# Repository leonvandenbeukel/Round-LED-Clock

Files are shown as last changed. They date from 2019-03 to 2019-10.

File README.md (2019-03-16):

# Wi-Fi Connected Round-LED-Clock
 
 ### Schema
 
 Connect 5 volts from the micro usb breakout board to the 5 volt pin on the ESP module.  
 Connect Ground from the micro usb breakout board to the Ground on the ESP module.  
 Connect 5 volts from the usb breakout board to 5 volt on the LED strip.  
 Connect Ground from the usb breakout board to Ground on the LED strip.  
 Connect pin D6 from the ESP module to the Data line on the LED strip.  
 
 ### Parts list (just Google on the name to find a link where to buy)

| Components                              			       |
| -------------                          			        |
| WeMOS D1 Mini ESP module               			        |
| LED strip WS2812B 60 RGB LED's 1 meter            |
| Black PLA filament                           		   |
| White PLA filament                           		   |
| 4x M3 screws                                      |
| 5 Volt power adapter                              |
| Micro USB cable                                   |
| Jumper wires                                      |
| Mini breadboard                                   |
| Micro USB breakout board                          |

### YouTube video

<a href="https://youtu.be/Z4b4v84smpg" target="_blank">Click to view: LED Clock</a>

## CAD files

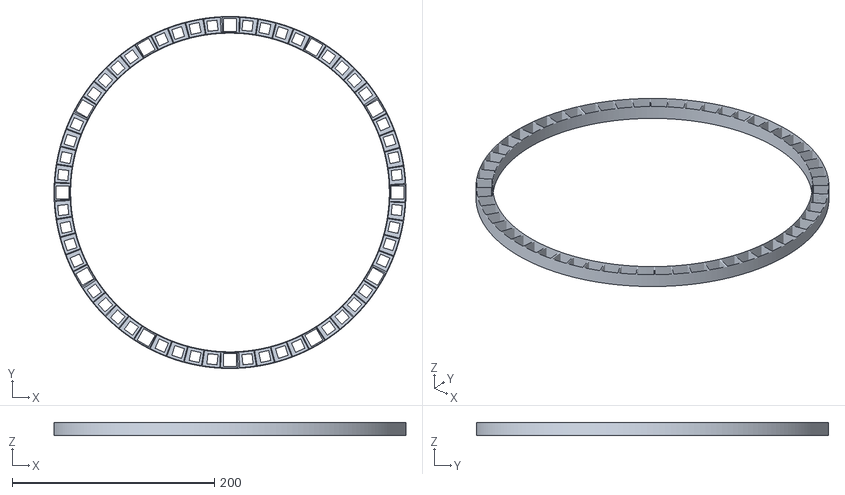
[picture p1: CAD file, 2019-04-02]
STL/Segment complete.stl
348.1 x 348.1 x 13.2

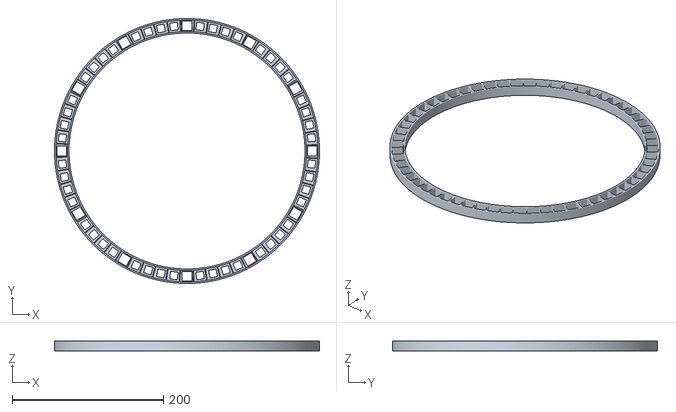
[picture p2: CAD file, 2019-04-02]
STL/Segment complete thicker wall.stl
350.9 x 350.9 x 13.2

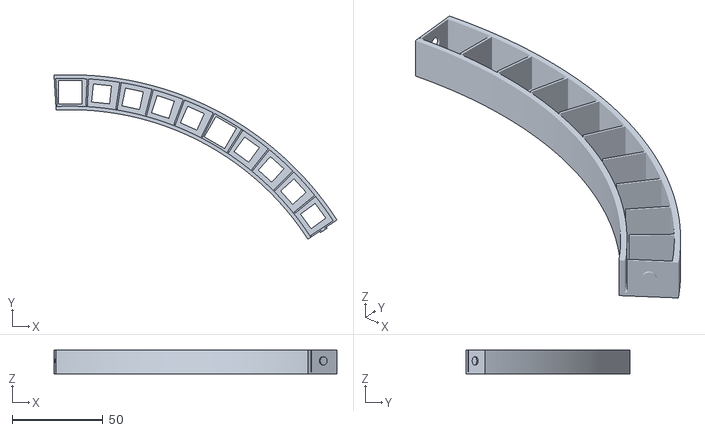
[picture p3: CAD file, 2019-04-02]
STL/Segment thicker wall.stl
156.2 x 90.7 x 13.2

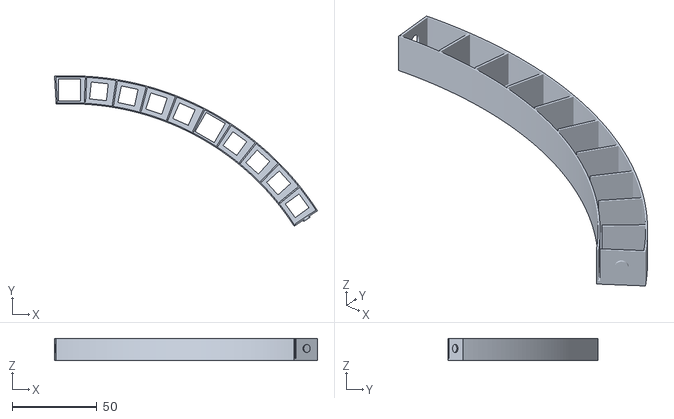
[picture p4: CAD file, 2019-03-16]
STL/Segment.stl
154.9 x 88.6 x 13.2

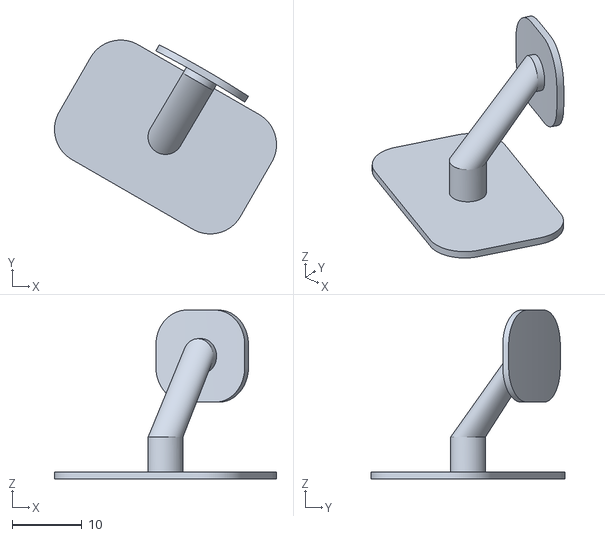
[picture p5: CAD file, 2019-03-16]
STL/Holder Small.stl
31.8 x 27.8 x 24.2

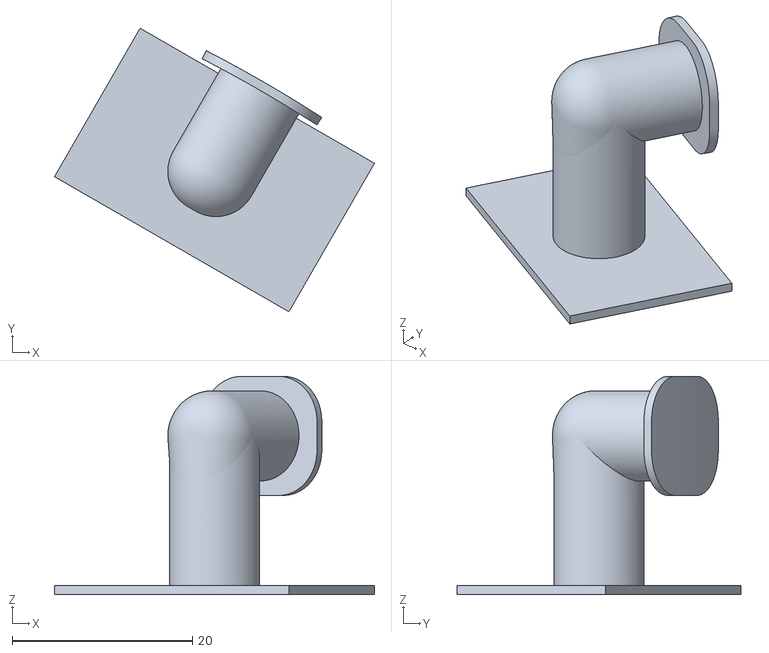
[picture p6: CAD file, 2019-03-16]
STL/Holder Large.stl
35.5 x 31.4 x 24.2

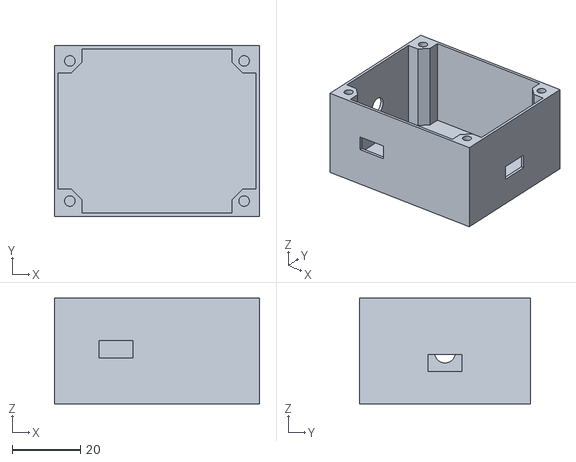
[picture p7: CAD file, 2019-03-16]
STL/Box.stl
60.0 x 50.0 x 31.0

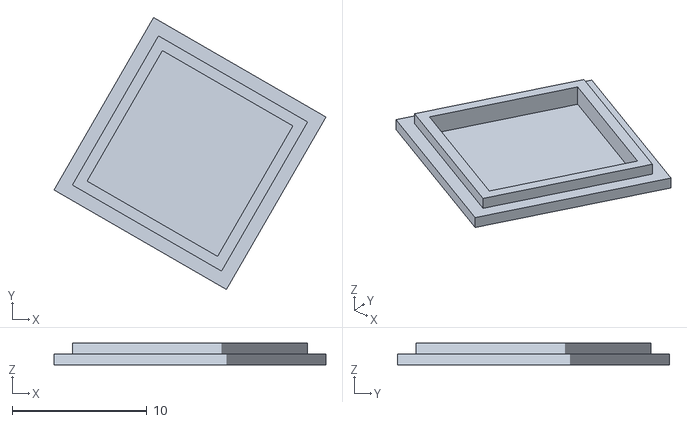
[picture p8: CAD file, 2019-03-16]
STL/Cover Large.stl
20.2 x 20.2 x 1.60

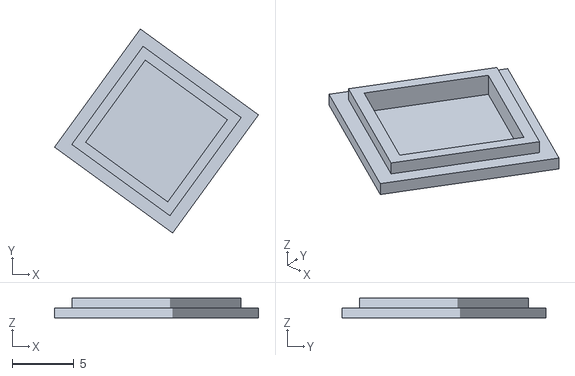
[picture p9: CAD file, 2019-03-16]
STL/Cover Small.stl
16.5 x 16.5 x 1.60

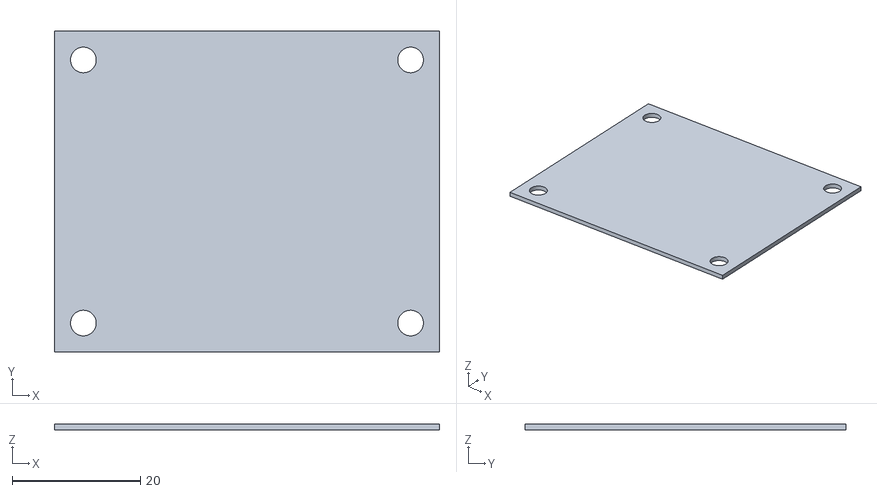
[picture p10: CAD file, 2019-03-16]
STL/Lid.stl
60.0 x 50.0 x 1.00

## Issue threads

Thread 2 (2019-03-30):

File request and your SMTP could be down

potter-91, 2019-03-30:
Hi Leon,

I tried to send a mail to your youtube mail, the mail got a delivery error at your smtp server.
So here is my mail:

Would it be possible that you can please send mir your Fusion Project or the files as steps?
I want to print the hole ring in one part beacause m Printer is so big ^^

Greeting from Germany ^^

leonvandenbeukel, 2019-04-02:
Hi,

I've added a complete ring for you to print in the STL files. Also added a segment with thicker walls as someone else requested.

Greetings from the Netherlands :-)
Leon

Closed 2019-04-02.

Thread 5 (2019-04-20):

Frequent Change to false time

arne4, 2019-04-20:
The LEDs show a wrong time every few minutes or seconds. This false indication lasts less than a second.
- I replaced the wemos, but nothing has changed.
- Solder connection also new and no change

Is this behaviour known or what else could it be?
Normally I would guess a problem with the wemos, but that should be excluded.

Thank you, Arne

ThEWiZ76, 2019-04-21:
Same problem here https://www.youtube.com/watch?v=w4xsj8hr7YY

ThEWiZ76, 2019-04-21:
I've merged the nighttime/hour gold/colormixing pull requests in the version I am running, then the problem is more visible. It looks like the whole register shifts forward. I think it's a FastLED lib issue rather than the code of this project. I currently use 3.1.6 and you?

ThEWiZ76, 2019-04-22:
I've done a little bit of reading, some people say the issue can occur when the power supply to the led strip isn't sufficient. I have upgraded my library to 3.2.6 and my issue is resolved.

arne4, 2019-04-23:
I upgraded to 3.2.6 and changed the power supply (also with direct supply of the LEDs) but unfortunately no change in behaviour....

:(
Such a beautiful clock, but currently it is not working!

arne4, 2019-04-23:
I just realised, that my IDE tricked me... I thought I updated to 3.2.6, but actually I still stick to the old FASTled library.
NOW, I updated and also everything is fine!
Thanks for this wonderful clock!
Arne

Closed 2019-04-23.

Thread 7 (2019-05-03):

Hour LED moving between hours

tomtaa, 2019-05-03:
Great work, but one issue:
At a normal analog clock the hour hand moves always.
e.g. at 9:30 the big hand is between 9 and 10.
At your device it stays on the 9.
Special at e.g. 9:55 your hour hand stays at 9; at the analog clock it stays directly before 10.

It's a little bit unusual.

Mahekrana, 2019-05-04:
can you share  videoof program uploadin eps8266 board

tomtaa, 2019-05-05:
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

I show here a sketch about that, what I mean. It's no technical problem with the clock; it's only a different to a normal analog clock. Maybe it's also a pull request and no issue.

arne4, 2019-05-05:
Hi,
as I understood the hour LED is not moving within the 5 possible positions during the course of the 60 min.
You would expect, that every ~15 min the hour LED moves towards the next Hour; the current sketch does not provide this functionality. The hour LED stays on the same spot for 1 hour and then moves 5 positions further.

Maybe someone can update the sketch with the following functionality:
1) introduce an hour_offset value
2)    if (minute>=10)
    hour_offset=(minute / 10)-1;
  else
    hour_offset=0;
3) hour_offset should move the hour LED acc to the value in hour_offset.

I am currently trying to update the sketch, but unfortunately (until now) I am not successfull ;)

tomtaa, 2019-05-05:
So, I play a little bit

and add one value and one additional row.

it seems to work, but I don't know if it works in all cases.
Maybe someone has the profi solution.
row 112 ff

`    for (int i=0; i<NUM_LEDS; i++)
      LEDs[i] = CRGB::Black;

      LEDs[getLEDMinuteOrSecond(currentDateTime.second)] = colorSecond;
      int stunde = (getLEDHour(currentDateTime.hour) + (currentDateTime.minute / 12)); //to move the Big Hand every 12 minutes
      LEDs[stunde] = colorHour; //to move the Big Hand every 12 minutes
    //LEDs[getLEDHour(currentDateTime.hour)] = colorHour; //Original

    LEDs[getLEDMinuteOrSecond(currentDateTime.minute)] = colorMinute;

    FastLED.show();`

arne4, 2019-05-06:
Hi there,

tried to get it running, but with no luck :(
I have two Hour spots now...
(tried to incrporate your into the existing code...)

Thank you, Arne

leonvandenbeukel, 2019-05-10:
Thanks for the suggestion and ideas! I've modified the code, you can use USE_LED_MOVE_BETWEEN_HOURS to enable this option.

Closed 2019-05-10.

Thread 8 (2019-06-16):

Newbie error in  compiling/flashing

RafaelCota, 2019-06-16:
Hi,
I'm trying to flash the program to the controller, but I'm getting some errors (files attached)

I was wondering if you could put me in the right track. I really want to get this project done. It's a good one.

Thank you in advanced,

[Errors-NonVerbose.pdf](https://github.com/leonvandenbeukel/Round-LED-Clock/files/3294463/Errors-NonVerbose.pdf)
[Errors-Verbose.pdf](https://github.com/leonvandenbeukel/Round-LED-Clock/files/3294464/Errors-Verbose.pdf)

leonvandenbeukel, 2019-06-16:
Hi,

If you use a generic esp board you probably cannot use pin D6, try using
only the pin number.

Regards,
Leon

Op zo 16 jun. 2019 20:45 schreef RafaelCota <notifications@github.com>:

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

Closed 2019-10-06.

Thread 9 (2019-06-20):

compilation error

Pierre01480, 2019-06-20:
Hello Leon,
I am admiring of all yours creations . Great !
I would like to make the WIFI clock (with the Wemos d1 mini board)
I selected the board LOLIN (Wemos) D1 R2 & mini (in the choise list of boards there is no Wemos D1 mini)
Below is the error message when compiling
Since 3 weeks I try to solve the problem .... Without success
If I use the library Adafruit_Neopixel (of course by modifying your program a bit): it works .... But I would like to understand my mistake
Thanks for your help

[errors.pdf](https://github.com/leonvandenbeukel/Round-LED-Clock/files/3310986/errors.pdf)

ThEWiZ76, 2019-06-21:
You should upgrade your fastled library to at least 3.2.6

Pierre01480, 2019-06-21:
thanks a lot for your help

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

Closed 2019-10-06.

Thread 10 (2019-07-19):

.

alhaddar, 2019-07-19:

alhaddar, 2019-07-19:
The problem has been resolved

alhaddar, 2019-07-20:
In file included from C:\Users\alhaddar\Round-LED-Clock_f-home2\Round-LED-Clock_f-home2.ino:18:0:

C:\Users\alhaddar\Documents\Arduino\libraries\FastLED/FastLED.h:14:21: note: #pragma message: FastLED version 3.002.010

 #    pragma message "FastLED version 3.002.010"

                     ^

In file included from C:\Users\alhaddar\Documents\Arduino\libraries\FastLED/FastLED.h:65:0,

                 from C:\Users\alhaddar\Round-LED-Clock_f-home2\Round-LED-Clock_f-home2.ino:18:

C:\Users\alhaddar\Documents\Arduino\libraries\FastLED/fastspi.h:115:23: note: #pragma message: No hardware SPI pins defined.  All SPI access will default to bitbanged output

 #      pragma message "No hardware SPI pins defined.  All SPI access will default to bitbanged output"

                       ^

Closed 2019-07-20.

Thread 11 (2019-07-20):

#pragma message: FastLED version 3.002.010

alhaddar, 2019-07-20:
Hi
Hi
When I'm sending programs to the Arduino show me this message

In file included from C:\Users\alhaddar\Round-LED-Clock_f-home2\Round-LED-Clock_f-home2.ino:18:0:

C:\Users\alhaddar\Documents\Arduino\libraries\FastLED/FastLED.h:14:21: note: #pragma message: FastLED version 3.002.010

 #    pragma message "FastLED version 3.002.010"

                     ^

In file included from C:\Users\alhaddar\Documents\Arduino\libraries\FastLED/FastLED.h:65:0,

                 from C:\Users\alhaddar\Round-LED-Clock_f-home2\Round-LED-Clock_f-home2.ino:18:

C:\Users\alhaddar\Documents\Arduino\libraries\FastLED/fastspi.h:115:23: note: #pragma message: No hardware SPI pins defined.  All SPI access will default to bitbanged output

 #      pragma message "No hardware SPI pins defined.  All SPI access will default to bitbanged output"

                       ^

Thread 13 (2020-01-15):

Minute and hour hand jumps to new position when second is at 59 and sometimes 30.

jldortch, 2020-01-15:
After resolving my initial problem my libraries, I built two clocks. both have the same strange action at the same times. condition only lasts for the one second...

Japyh, 2021-01-15:
Hi,
I have used the code for another clock design but the coding is the same. I measured the same problem of switching hours to the section of minutes after some time.
The code was implemented 1:1 and I use a APA106 F5 Led string which is controlled by the library fastLED and the SK6822 chipset.
Has somebody an idea of how to solv it?

Thanks in advance for an answer and best regards,
JP

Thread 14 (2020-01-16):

'D6' was not declared in this scope

rf5g, 2020-01-16:
when sending i have this error:
'D6' was not declared in this scope

i try:
#define DATA_PIN 6
error:
Compilation Error for Generic ESP8266 Module Board.

how i can solve this problem?

rf5g, 2020-01-17:
Because my ESP8266 Mini d1 have different pin names. D6 = gpio12. Sorry...

Closed 2020-01-17.

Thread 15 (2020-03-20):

DATA_PIN not defined in the scope

raviteja2110, 2020-03-20:
Round-LED-Clock:81:18: error: 'D6' was not declared in this scope

 #define DATA_PIN D6

Pijuli, 2020-03-21:
Same here :(

Pijuli, 2020-03-21:
Using ESP8266 D1 mini
This is what I'm getting. Any idea?

`Arduino:1.8.12 (Windows 10), Tarjeta:"Generic ESP8266 Module, 80 MHz, Flash, Legacy (new can return nullptr), All SSL ciphers (most compatible), dtr (aka nodemcu), 26 MHz, 40MHz, DOUT (compatible), 1MB (FS:64KB OTA:~470KB), 2, nonos-sdk 2.2.1+100 (190703), v2 Lower Memory, Disabled, None, Only Sketch, 115200"

In file included from C:\Users\Pijuli\Documents\Arduino\projectes\Round-LED-Clock\Round-LED-Clock.ino:18:0:

C:\Users\Pijuli\Documents\Arduino\libraries\FastLED/FastLED.h:14:21: note: #pragma message: FastLED version 3.003.003

 #    pragma message "FastLED version 3.003.003"

                     ^

In file included from C:\Users\Pijuli\Documents\Arduino\libraries\FastLED/FastLED.h:65:0,

                 from C:\Users\Pijuli\Documents\Arduino\projectes\Round-LED-Clock\Round-LED-Clock.ino:18:

C:\Users\Pijuli\Documents\Arduino\libraries\FastLED/fastspi.h:130:23: note: #pragma message: No hardware SPI pins defined.  All SPI access will default to bitbanged output

 #      pragma message "No hardware SPI pins defined.  All SPI access will default to bitbanged output"

                       ^

C:\Users\Pijuli\Documents\Arduino\projectes\Round-LED-Clock\Round-LED-Clock.ino: In function 'void setup()':

Round-LED-Clock:63:18: error: 'D6' was not declared in this scope

 #define DATA_PIN D6

                  ^

C:\Users\Pijuli\Documents\Arduino\projectes\Round-LED-Clock\Round-LED-Clock.ino:81:28: note: in expansion of macro 'DATA_PIN'

   FastLED.addLeds<WS2812B, DATA_PIN, GRB>(LEDs, NUM_LEDS);

                            ^

Round-LED-Clock:81:57: error: no matching function for call to 'CFastLED::addLeds(CRGB [60], int)'

   FastLED.addLeds<WS2812B, DATA_PIN, GRB>(LEDs, NUM_LEDS);

                                                         ^

C:\Users\Pijuli\Documents\Arduino\projectes\Round-LED-Clock\Round-LED-Clock.ino:81:57: note: candidates are:

In file included from C:\Users\Pijuli\Documents\Arduino\projectes\Round-LED-Clock\Round-LED-Clock.ino:18:0:

C:\Users\Pijuli\Documents\Arduino\libraries\FastLED/FastLED.h:223:130: note: template<ESPIChipsets CHIPSET, unsigned char DATA_PIN, unsigned char CLOCK_PIN, EOrder RGB_ORDER, unsigned int SPI_DATA_RATE> CLEDController& CFastLED::addLeds(CRGB*, int, int)

  template<ESPIChipsets CHIPSET,  uint8_t DATA_PIN, uint8_t CLOCK_PIN, EOrder RGB_ORDER, uint32_t SPI_DATA_RATE > CLEDController &addLeds(struct CRGB *data, int nLedsOrOffset, int nLedsIfOffset = 0) {

                                                                                                                                  ^

C:\Users\Pijuli\Documents\Arduino\libraries\FastLED/FastLED.h:223:130: note:   template argument deduction/substitution failed:

Round-LED-Clock:81:57: error: template argument 2 is invalid

   FastLED.addLeds<WS2812B, DATA_PIN, GRB>(LEDs, NUM_LEDS);

                                                         ^

In file included from C:\Users\Pijuli\Documents\Arduino\projectes\Round-LED-Clock\Round-LED-Clock.ino:18:0:

C:\Users\Pijuli\Documents\Arduino\libraries\FastLED/FastLED.h:237:95: note: template<ESPIChipsets CHIPSET, unsigned char DATA_PIN, unsigned char CLOCK_PIN> static CLEDController& CFastLED::addLeds(CRGB*, int, int)

  template<ESPIChipsets CHIPSET,  uint8_t DATA_PIN, uint8_t CLOCK_PIN > static CLEDController &addLeds(struct CRGB *data, int nLedsOrOffset, int nLedsIfOffset = 0) {

                                                                                               ^

C:\Users\Pijuli\Documents\Arduino\libraries\FastLED/FastLED.h:237:95: note:   template argument deduction/substitution failed:

Round-LED-Clock:81:57: error: template argument 2 is invalid

   FastLED.addLeds<WS2812B, DATA_PIN, GRB>(LEDs, NUM_LEDS);

                                                         ^

In file included from C:\Users\Pijuli\Documents\Arduino\projectes\Round-LED-Clock\Round-LED-Clock.ino:18:0:

C:\Users\Pijuli\Documents\Arduino\libraries\FastLED/FastLED.h:251:113: note: template<ESPIChipsets CHIPSET, unsigned char DATA_PIN, unsigned char CLOCK_PIN, EOrder RGB_ORDER> static CLEDController& CFastLED::addLeds(CRGB*, int, int)

  template<ESPIChipsets CHIPSET,  uint8_t DATA_PIN, uint8_t CLOCK_PIN, EOrder RGB_ORDER > static CLEDController &addLeds(struct CRGB *data, int nLedsOrOffset, int nLedsIfOffset = 0) {

                                                                                                                 ^

C:\Users\Pijuli\Documents\Arduino\libraries\FastLED/FastLED.h:251:113: note:   template argument deduction/substitution failed:

Round-LED-Clock:81:57: error: template argument 2 is invalid

   FastLED.addLeds<WS2812B, DATA_PIN, GRB>(LEDs, NUM_LEDS);

                                                         ^

In file included from C:\Users\Pijuli\Documents\Arduino\projectes\Round-LED-Clock\Round-LED-Clock.ino:18:0:

C:\Users\Pijuli\Documents\Arduino\libraries\FastLED/FastLED.h:301:25: note: template<template<unsigned char DATA_PIN, EOrder RGB_ORDER> class CHIPSET, unsigned char DATA_PIN, EOrder RGB_ORDER> static CLEDController& CFastLED::addLeds(CRGB*, int, int)

  static CLEDController &addLeds(struct CRGB *data, int nLedsOrOffset, int nLedsIfOffset = 0) {

                         ^

C:\Users\Pijuli\Documents\Arduino\libraries\FastLED/FastLED.h:301:25: note:   template argument deduction/substitution failed:

Round-LED-Clock:81:57: error: template argument 2 is invalid

   FastLED.addLeds<WS2812B, DATA_PIN, GRB>(LEDs, NUM_LEDS);

                                                         ^

In file included from C:\Users\Pijuli\Documents\Arduino\projectes\Round-LED-Clock\Round-LED-Clock.ino:18:0:

C:\Users\Pijuli\Documents\Arduino\libraries\FastLED/FastLED.h:307:25: note: template<template<unsigned char DATA_PIN, EOrder RGB_ORDER> class CHIPSET, unsigned char DATA_PIN> static CLEDController& CFastLED::addLeds(CRGB*, int, int)

  static CLEDController &addLeds(struct CRGB *data, int nLedsOrOffset, int nLedsIfOffset = 0) {

                         ^

C:\Users\Pijuli\Documents\Arduino\libraries\FastLED/FastLED.h:307:25: note:   template argument deduction/substitution failed:

Round-LED-Clock:81:57: error: wrong number of template arguments (3, should be 2)

   FastLED.addLeds<WS2812B, DATA_PIN, GRB>(LEDs, NUM_LEDS);

                                                         ^

In file included from C:\Users\Pijuli\Documents\Arduino\projectes\Round-LED-Clock\Round-LED-Clock.ino:18:0:

C:\Users\Pijuli\Documents\Arduino\libraries\FastLED/FastLED.h:313:25: note: template<template<unsigned char DATA_PIN> class CHIPSET, unsigned char DATA_PIN> static CLEDController& CFastLED::addLeds(CRGB*, int, int)

  static CLEDController &addLeds(struct CRGB *data, int nLedsOrOffset, int nLedsIfOffset = 0) {

                         ^

C:\Users\Pijuli\Documents\Arduino\libraries\FastLED/FastLED.h:313:25: note:   template argument deduction/substitution failed:

Round-LED-Clock:81:57: error: wrong number of template arguments (3, should be 2)

   FastLED.addLeds<WS2812B, DATA_PIN, GRB>(LEDs, NUM_LEDS);

                                                         ^

In file included from C:\Users\Pijuli\Documents\Arduino\projectes\Round-LED-Clock\Round-LED-Clock.ino:18:0:

C:\Users\Pijuli\Documents\Arduino\libraries\FastLED/FastLED.h:357:25: note: template<template<EOrder RGB_ORDER> class CHIPSET, EOrder RGB_ORDER> static CLEDController& CFastLED::addLeds(CRGB*, int, int)

  static CLEDController &addLeds(struct CRGB *data, int nLedsOrOffset, int nLedsIfOffset = 0) {

                         ^

C:\Users\Pijuli\Documents\Arduino\libraries\FastLED/FastLED.h:357:25: note:   template argument deduction/substitution failed:

Round-LED-Clock:81:57: error: wrong number of template arguments (3, should be 2)

   FastLED.addLeds<WS2812B, DATA_PIN, GRB>(LEDs, NUM_LEDS);

                                                         ^

In file included from C:\Users\Pijuli\Documents\Arduino\projectes\Round-LED-Clock\Round-LED-Clock.ino:18:0:

C:\Users\Pijuli\Documents\Arduino\libraries\FastLED/FastLED.h:363:25: note: template<template<EOrder RGB_ORDER> class CHIPSET> static CLEDController& CFastLED::addLeds(CRGB*, int, int)

  static CLEDController &addLeds(struct CRGB *data, int nLedsOrOffset, int nLedsIfOffset = 0) {

                         ^

C:\Users\Pijuli\Documents\Arduino\libraries\FastLED/FastLED.h:363:25: note:   template argument deduction/substitution failed:

Round-LED-Clock:81:57: error: wrong number of template arguments (3, should be 1)

   FastLED.addLeds<WS2812B, DATA_PIN, GRB>(LEDs, NUM_LEDS);

                                                         ^

In file included from C:\Users\Pijuli\Documents\Arduino\projectes\Round-LED-Clock\Round-LED-Clock.ino:18:0:

C:\Users\Pijuli\Documents\Arduino\libraries\FastLED/FastLED.h:431:25: note: template<EBlockChipsets CHIPSET, int NUM_LANES, EOrder RGB_ORDER> static CLEDController& CFastLED::addLeds(CRGB*, int, int)

  static CLEDController &addLeds(struct CRGB *data, int nLedsOrOffset, int nLedsIfOffset = 0) {

                         ^

C:\Users\Pijuli\Documents\Arduino\libraries\FastLED/FastLED.h:431:25: note:   template argument deduction/substitution failed:

Round-LED-Clock:81:57: error: template argument 2 is invalid

   FastLED.addLeds<WS2812B, DATA_PIN, GRB>(LEDs, NUM_LEDS);

                                                         ^

In file included from C:\Users\Pijuli\Documents\Arduino\projectes\Round-LED-Clock\Round-LED-Clock.ino:18:0:

C:\Users\Pijuli\Documents\Arduino\libraries\FastLED/FastLED.h:472:25: note: template<EBlockChipsets CHIPSET, int NUM_LANES> static CLEDController& CFastLED::addLeds(CRGB*, int, int)

  static CLEDController &addLeds(struct CRGB *data, int nLedsOrOffset, int nLedsIfOffset = 0) {

                         ^

C:\Users\Pijuli\Documents\Arduino\libraries\FastLED/FastLED.h:472:25: note:   template argument deduction/substitution failed:

Round-LED-Clock:81:57: error: wrong number of template arguments (3, should be 2)

   FastLED.addLeds<WS2812B, DATA_PIN, GRB>(LEDs, NUM_LEDS);

                                                         ^

exit status 1
'D6' was not declared in this scope

Este informe podría contener más información con
"Mostrar salida detallada durante la compilación"
opción habilitada en Archivo -> Preferencias.
`

Pijuli, 2020-03-21:
Fixed.
I was using the wrong ESP8266 board
Tripple check your board. In my case WEMOS D1 R2 & Mini

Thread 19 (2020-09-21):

No issue, works well, would move to see mqtt support to change colours, WiFi info etc on the fly 😁

Phatsyd, 2020-09-21:

BlackCatPeanut, 2021-01-01:
Keeping an eye on this project for HA integration. Super cool idea to allow for more finite control of timer, brightness etc. For the moment I’ll enjoy it non-integrated.

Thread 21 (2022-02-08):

It is not working for me only the first led is turning green ,its connecting to wifi but no output

kankapee, 2022-02-08:

JSB129, 2022-03-18:
try rolling back the version of FastLED, I am on 3.2.X

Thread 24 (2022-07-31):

Just getting LEDs lighting all in green

cmora111, 2022-07-31:
I had the clock working fine for months. Then after an update The LEDs light as if it was waiting for NTP. I've put printlns in and found that it is not refreshing properly. The printlns are before and after the show in loop(). but it is only lighting up all LEDs green

I am using an Adafruit Feather Huzzan ESP8266

cmora111, 2022-08-05:
Code:
...
    if ( night() && USE_NIGHTCUTOFF == true )
      FastLED.setBrightness (NIGHTBRIGHTNESS);

    Serial.println("Just before FastLED.show");
    FastLED.show();
    Serial.println("Just after FastLED.show");
  }
}

byte getLEDHour(byte hours, byte minutes) {
....

20:51:07.705 -> Just after FastLED.show
20:51:08.702 -> 2022 8 4 21 51 8 day of week: 5 summer time: 1 night time: 1
20:51:08.702 -> 192.168.x.x
20:51:08.702 -> Time server IP:	45.33.37.82
20:51:08.702 -> Just before FastLED.show
20:51:08.702 -> Just after FastLED.show
20:51:09.698 -> 2022 8 4 21 51 9 day of week: 5 summer time: 1 night time: 1

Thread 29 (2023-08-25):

interval ntp issue

ani123446, 2023-08-25:
hello everyone,
                        Am from India. Can anyone help me with line 25. what should I put there if am from India.

**unsigned long intervalNTP = 24 * 60 * 60000;      // Request a new NTP time every 24 hours**

brettoliver, 2023-08-26:
I would have thought you want to change line 23?
 unsigned long timeZone = 1.0;               // Change this value to your local timezone (in my case +1 for Amsterdam)

ani123446, 2023-08-26:
My clock is working but the time is not proper even though i change to my time zone. (Its +5:30 for india). But idk abt that line 25 what should i put there?

brettoliver, 2023-08-26:
Line 25 is the interval that the clock checks the NTP time. it is set to check once every 24 hours.
What time is your clock showing and what is the local time?

brettoliver, 2023-08-26:
Line 24 Is this set to you local time server?   in.pool.ntp.org

Set this to a ntpserver nearby, check this site for a list of servers: https://www.pool.ntp.org/en/

ani123446, 2023-08-26:
yes line 24 is set to my local server (in.pool.ntp.org). My time here is 10:13 but its showing around 5:23

brettoliver, 2023-08-26:
Have you typed in +5.5 or  just 5.5?  Try changing it. I'm just guessing here.

ani123446, 2023-08-26:
in india utc is 5.30

brettoliver, 2023-08-26:
yeah 0.3 is 0.5 in hours? Maybe why your minutes are out?

ani123446, 2023-08-26:
yes 0.3 in hours.

brettoliver, 2023-08-26:
Can you paste your code?

ani123446, 2023-08-26:
/*
  WiFi connected round LED Clock. It gets NTP time from the internet and translates to a 60 RGB WS2812B LED strip.

  If you have another orientation where the wire comes out then change the methods getLEDHour and getLEDMinuteOrSecond

  Happy programming, Leon van den Beukel, march 2019

  ---
  NTP and summer time code based on:
  https://tttapa.github.io/ESP8266/Chap15%20-%20NTP.html
  https://github.com/SensorsIot/NTPtimeESP/blob/master/NTPtimeESP.cpp (for US summer time support check this link)

*/

#include <ESP8266WiFi.h>
#include <ESP8266WiFiMulti.h>
#include <WiFiUdp.h>
#include <FastLED.h>
#define DEBUG_ON

const char ssid[] = "Aniket";                          // Your network SSID name here
const char pass[] = "lalbalpal";                          // Your network password here
unsigned long timeZone = +5.30;                     // Change this value to your local timezone (in my case +1 for Amsterdam)
const char* NTPServerName = "in.pool.ntp.org";    // Change this to a ntpserver nearby, check this site for a list of servers: https://www.pool.ntp.org/en/
unsigned long intervalNTP =  24 * 60 * 60000;      // Request a new NTP time every 24 hours

// Change the colors here if you want.
// Check for reference: https://github.com/FastLED/FastLED/wiki/Pixel-reference#predefined-colors-list
// You can also set the colors with RGB values, for example red:
// CRGB colorHour = CRGB(255, 0, 0);
CRGB colorHour = CRGB::Red;
CRGB colorMinute = CRGB::Green;
CRGB colorSecond = CRGB::Blue;
CRGB colorHourMinute = CRGB::Yellow;
CRGB colorHourSecond = CRGB::Magenta;
CRGB colorMinuteSecond = CRGB::Cyan;
CRGB colorAll = CRGB::White;

// Set this to true if you want the hour LED to move between hours (if set to false the hour LED will only move every hour)
#define USE_LED_MOVE_BETWEEN_HOURS true

// Cutoff times for day / night brightness.
#define USE_NIGHTCUTOFF false   // Enable/Disable night brightness
#define MORNINGCUTOFF 8         // When does daybrightness begin?   8am
#define NIGHTCUTOFF 20          // When does nightbrightness begin? 10pm
#define NIGHTBRIGHTNESS 20      // Brightness level from 0 (off) to 255 (full brightness)

ESP8266WiFiMulti wifiMulti;             
WiFiUDP UDP;                            
IPAddress timeServerIP;                 
const int NTP_PACKET_SIZE = 48;         
byte NTPBuffer[NTP_PACKET_SIZE];        

unsigned long prevNTP = 0;
unsigned long lastNTPResponse = millis();
uint32_t timeUNIX = 0;
unsigned long prevActualTime = 0;

#define LEAP_YEAR(Y) ( ((1970+Y)>0) && !((1970+Y)%4) && ( ((1970+Y)%100) || !((1970+Y)%400) ) )
static const uint8_t monthDays[] = {31, 28, 31, 30, 31, 30, 31, 31, 30, 31, 30, 31};

#define NUM_LEDS 60
#define DATA_PIN D6
CRGB LEDs[NUM_LEDS];

struct DateTime {
  int  year;
  byte month;
  byte day;
  byte hour;
  byte minute;
  byte second;
  byte dayofweek;
};

DateTime currentDateTime;

void setup() {

  FastLED.delay(3000);
  FastLED.addLeds<WS2812B, DATA_PIN, GRB>(LEDs, NUM_LEDS);

  Serial.begin(115200);  
  delay(10);
  Serial.println("\r\n");

  startWiFi();
  startUDP();

  if(!WiFi.hostByName(NTPServerName, timeServerIP)) {
    Serial.println("DNS lookup failed. Rebooting.");
    Serial.flush();
    ESP.reset();
  }
  Serial.print("Time server IP:\t");
  Serial.println(timeServerIP);

  Serial.println("\r\nSending NTP request ...");
  sendNTPpacket(timeServerIP);
}

void loop() {
  unsigned long currentMillis = millis();

  if (currentMillis - prevNTP > intervalNTP) { // If a minute has passed since last NTP request
    prevNTP = currentMillis;
    Serial.println("\r\nSending NTP request ...");
    sendNTPpacket(timeServerIP);               // Send an NTP request
  }

  uint32_t time = getTime();                   // Check if an NTP response has arrived and get the (UNIX) time
  if (time) {                                  // If a new timestamp has been received
    timeUNIX = time;
    Serial.print("NTP response:\t");
    Serial.println(timeUNIX);
    lastNTPResponse = currentMillis;
  } else if ((currentMillis - lastNTPResponse) > 3600000) {
    Serial.println("More than 1 hour since last NTP response. Rebooting.");
    Serial.flush();
    ESP.reset();
  }

  uint32_t actualTime = timeUNIX + (currentMillis - lastNTPResponse)/1000;
  if (actualTime != prevActualTime && timeUNIX != 0) { // If a second has passed since last update
    prevActualTime = actualTime;
    convertTime(actualTime);

    for (int i=0; i<NUM_LEDS; i++)
      LEDs[i] = CRGB::Black;

    int second = getLEDMinuteOrSecond(currentDateTime.second);
    int minute = getLEDMinuteOrSecond(currentDateTime.minute);
    int hour = getLEDHour(currentDateTime.hour, currentDateTime.minute);

    // Set "Hands"
    LEDs[second] = colorSecond;
    LEDs[minute] = colorMinute;
    LEDs[hour] = colorHour;

    // Hour and min are on same spot
    if ( hour == minute)
      LEDs[hour] = colorHourMinute;

    // Hour and sec are on same spot
    if ( hour == second)
      LEDs[hour] = colorHourSecond;

    // Min and sec are on same spot
    if ( minute == second)
      LEDs[minute] = colorMinuteSecond;

    // All are on same spot
    if ( minute == second && minute == hour)
      LEDs[minute] = colorAll;

    if ( night() && USE_NIGHTCUTOFF == true )
      FastLED.setBrightness (NIGHTBRIGHTNESS);

    FastLED.show();
  }
}

byte getLEDHour(byte hours, byte minutes) {
  if (hours > 12)
    hours = hours - 12;

  byte hourLED;
  if (hours <= 5)
    hourLED = (hours * 5) + 30;
  else
    hourLED = (hours * 5) - 30;

  if (USE_LED_MOVE_BETWEEN_HOURS == true) {
    if        (minutes >= 12 && minutes < 24) {
      hourLED += 1;
    } else if (minutes >= 24 && minutes < 36) {
      hourLED += 2;
    } else if (minutes >= 36 && minutes < 48) {
      hourLED += 3;
    } else if (minutes >= 48) {
      hourLED += 4;
    }
  }

  return hourLED;
}

byte getLEDMinuteOrSecond(byte minuteOrSecond) {
  if (minuteOrSecond < 30)
    return minuteOrSecond + 30;
  else
    return minuteOrSecond - 30;
}

void startWiFi() {
  wifiMulti.addAP(ssid, pass);

  Serial.println("Connecting");
  byte i = 0;
  while (wifiMulti.run() != WL_CONNECTED) {
    delay(250);
    Serial.print('.');
    LEDs[i++] = CRGB::Green;
    FastLED.show();
  }
  Serial.println("\r\n");
  Serial.print("Connected to ");
  Serial.println(WiFi.SSID());     
  Serial.print("IP address:\t");
  Serial.print(WiFi.localIP());    
  Serial.println("\r\n");
}

void startUDP() {
  Serial.println("Starting UDP");
  UDP.begin(123);                          // Start listening for UDP messages on port 123
  Serial.print("Local port:\t");
  Serial.println(UDP.localPort());
  Serial.println();
}

uint32_t getTime() {
  if (UDP.parsePacket() == 0) { // If there's no response (yet)
    return 0;
  }
  UDP.read(NTPBuffer, NTP_PACKET_SIZE); // read the packet into the buffer
  // Combine the 4 timestamp bytes into one 32-bit number
  uint32_t NTPTime = (NTPBuffer[40] << 24) | (NTPBuffer[41] << 16) | (NTPBuffer[42] << 8) | NTPBuffer[43];
  // Convert NTP time to a UNIX timestamp:
  // Unix time starts on Jan 1 1970. That's 2208988800 seconds in NTP time:
  const uint32_t seventyYears = 2208988800UL;
  // subtract seventy years:
  uint32_t UNIXTime = NTPTime - seventyYears;
  return UNIXTime;
}

void sendNTPpacket(IPAddress& address) {
  memset(NTPBuffer, 0, NTP_PACKET_SIZE);  // set all bytes in the buffer to 0
  // Initialize values needed to form NTP request
  NTPBuffer[0] = 0b11100011;   // LI, Version, Mode
  // send a packet requesting a timestamp:
  UDP.beginPacket(address, 123); // NTP requests are to port 123
  UDP.write(NTPBuffer, NTP_PACKET_SIZE);
  UDP.endPacket();
}

void convertTime(uint32_t time) {
  // Correct time zone
  time += (3600 * timeZone);

  currentDateTime.second = time % 60;
  currentDateTime.minute = time / 60 % 60;
  currentDateTime.hour   = time / 3600 % 24;
  time  /= 60;  // To minutes
  time  /= 60;  // To hours
  time  /= 24;  // To days
  currentDateTime.dayofweek = ((time + 4) % 7) + 1;
  int year = 0;
  int days = 0;
  while ((unsigned)(days += (LEAP_YEAR(year) ? 366 : 365)) <= time) {
    year++;
  }
  days -= LEAP_YEAR(year) ? 366 : 365;
  time  -= days; // To days in this year, starting at 0
  days = 0;
  byte month = 0;
  byte monthLength = 0;
  for (month = 0; month < 12; month++) {
    if (month == 1) { // February
      if (LEAP_YEAR(year)) {
        monthLength = 29;
      } else {
        monthLength = 28;
      }
    } else {
      monthLength = monthDays[month];
    }

    if (time >= monthLength) {
      time -= monthLength;
    } else {
      break;
    }
  }

  currentDateTime.day = time + 1;
  currentDateTime.year = year + 1970;
  currentDateTime.month = month + 1;

  // Correct European Summer time
  if (summerTime()) {
    currentDateTime.hour += 1;
  }

#ifdef DEBUG_ON
  Serial.print(currentDateTime.year);
  Serial.print(" ");
  Serial.print(currentDateTime.month);
  Serial.print(" ");
  Serial.print(currentDateTime.day);
  Serial.print(" ");
  Serial.print(currentDateTime.hour);
  Serial.print(" ");
  Serial.print(currentDateTime.minute);
  Serial.print(" ");
  Serial.print(currentDateTime.second);
  Serial.print(" day of week: ");
  Serial.print(currentDateTime.dayofweek);
  Serial.print(" summer time: ");
  Serial.print(summerTime());
  Serial.print(" night time: ");
  Serial.print(night());
  Serial.println();
#endif
}

boolean summerTime() {
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
brettoliver, 2023-08-26:
I think 5.3 is 5 hours 20mins. 5.5 is 5hours 30mins? Try just 5.5 without the plus and see what time you get.

ani123446, 2023-08-26:
Its all the same. I have try this. I have done different  experiment by changing time and ntp sever. Now i got a time matches to our time but the its not our timezone. 😅
I change time zone to -2. And the server to (2.pool.ntp.org). Now am getting a correct time.

ani123446, 2023-08-26:
with 5.5 it coming 1.17but the time here is 12.47

brettoliver, 2023-08-26:
Have you tried 0 just to see what the NTP server gives out?

ani123446, 2023-08-26:
yes but correct time is not showing

ani123446, 2023-08-26:
with 4.50 or 4.5 or 4.30 its showing time but 30 mins fast from my country time

Boris-jivotnoe, 2023-12-12:
I have the same problem, the clock is 5 hours behind and the minutes are 30 minutes behind, the LED strip is the same as in the project, what can be done?

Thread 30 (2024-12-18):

Crashes

fabio323ti, 2024-12-18:
my esp8266 Nodemcu crashes.
someone can fix it?

log :
*wm:AutoConnect
*wm:No wifi saved, skipping
*wm:AutoConnect: FAILED for  105 ms
*wm:StartAP with SSID:  RC15580022
*wm:AP IP address: 192.168.4.1
Entered config mode
192.168.4.1
RC15580022
*wm:Starting Web Portal

--------------- CUT HERE FOR EXCEPTION DECODER ---------------
Soft WDT reset

Exception (4):
epc1=0x402131e0 epc2=0x00000000 epc3=0x00000000 excvaddr=0x00000000 depc=0x00000000

>>>stack>>>
3ffffea0:  3ffffec0 00000001 3fffff0c 00000000
3ffffeb0:  3ffeeeb8 3ffeeeb8 3ffeedb8 4020b9a0
3ffffec0:  00303831 3fffff0c 3fffff18 00000000
3ffffed0:  3ffeeeb8 00000020 3fff109c 40100ae8
3ffffee0:  3ffeeeb8 00000001 3fffff18 00000000
3ffffef0:  3ffeeeb8 00000001 3ffeedb8 4020bd1d
3fffff00:  00000000 73646e6f 00000000 00000000
3fffff10:  000b000f 00000000 00000000 000b000f
3fffff20:  00000000 00000000 0b020c49 00157314
3fffff30:  3fffff70 3ffe8807 00000001 3ffeed34
3fffff40:  00000000 00000000 00000000 3ffeed34
3fffff50:  3ffeedb8 3ffef118 3ffeec80 4020133d
3fffff60:  40201124 30303835 40213978 40213970
3fffff70:  35314352 30303835 0a003232 000de8c3
3fffff80:  ffffffff 00000000 3ffef1a0 3ffef36c
3fffff90:  3ffeec48 00000002 3ffef1a0 3ffef36c
3fffffa0:  3ffeec48 00000000 3ffef1a0 40202143
3fffffb0:  3fffdad0 00000000 3ffef340 40210cf0
3fffffc0:  feefeffe feefeffe 3fffdab0 40100e95
<<<stack<<<

--------------- CUT HERE FOR EXCEPTION DECODER ---------------
H�)�(����� D)�� $Iآ�

Input-BDF, 2024-12-22:
Please check https://github.com/tzapu/WiFiManager/issues/1718
Think this is related to your issue.

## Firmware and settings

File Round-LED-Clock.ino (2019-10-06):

/*
  WiFi connected round LED Clock. It gets NTP time from the internet and translates to a 60 RGB WS2812B LED strip.

  If you have another orientation where the wire comes out then change the methods getLEDHour and getLEDMinuteOrSecond

  Happy programming, Leon van den Beukel, march 2019

  ---  
  NTP and summer time code based on:
  https://tttapa.github.io/ESP8266/Chap15%20-%20NTP.html 
  https://github.com/SensorsIot/NTPtimeESP/blob/master/NTPtimeESP.cpp (for US summer time support check this link)  
  
*/

#include <ESP8266WiFi.h>
#include <ESP8266WiFiMulti.h>
#include <WiFiUdp.h>
#include <FastLED.h>
#define DEBUG_ON

const char ssid[] = "*";                          // Your network SSID name here
const char pass[] = "*";                          // Your network password here
unsigned long timeZone = 1.0;                     // Change this value to your local timezone (in my case +1 for Amsterdam)
const char* NTPServerName = "nl.pool.ntp.org";    // Change this to a ntpserver nearby, check this site for a list of servers: https://www.pool.ntp.org/en/
unsigned long intervalNTP = 24 * 60 * 60000;      // Request a new NTP time every 24 hours

// Change the colors here if you want.
// Check for reference: https://github.com/FastLED/FastLED/wiki/Pixel-reference#predefined-colors-list
// You can also set the colors with RGB values, for example red:
// CRGB colorHour = CRGB(255, 0, 0);
CRGB colorHour = CRGB::Red;
CRGB colorMinute = CRGB::Green;
CRGB colorSecond = CRGB::Blue;
CRGB colorHourMinute = CRGB::Yellow;
CRGB colorHourSecond = CRGB::Magenta;
CRGB colorMinuteSecond = CRGB::Cyan;
CRGB colorAll = CRGB::White;

// Set this to true if you want the hour LED to move between hours (if set to false the hour LED will only move every hour)
#define USE_LED_MOVE_BETWEEN_HOURS true

// Cutoff times for day / night brightness.
#define USE_NIGHTCUTOFF false   // Enable/Disable night brightness
#define MORNINGCUTOFF 8         // When does daybrightness begin?   8am
#define NIGHTCUTOFF 20          // When does nightbrightness begin? 10pm
#define NIGHTBRIGHTNESS 20      // Brightness level from 0 (off) to 255 (full brightness)

ESP8266WiFiMulti wifiMulti;                     
WiFiUDP UDP;                                    
IPAddress timeServerIP;                         
const int NTP_PACKET_SIZE = 48;                 
byte NTPBuffer[NTP_PACKET_SIZE];                

unsigned long prevNTP = 0;
unsigned long lastNTPResponse = millis();
uint32_t timeUNIX = 0;
unsigned long prevActualTime = 0;

#define LEAP_YEAR(Y) ( ((1970+Y)>0) && !((1970+Y)%4) && ( ((1970+Y)%100) || !((1970+Y)%400) ) )
static const uint8_t monthDays[] = {31, 28, 31, 30, 31, 30, 31, 31, 30, 31, 30, 31};

#define NUM_LEDS 60     
#define DATA_PIN D6
CRGB LEDs[NUM_LEDS];

struct DateTime {
  int  year;
  byte month;
  byte day;
  byte hour;
  byte minute;
  byte second;
  byte dayofweek;
};

DateTime currentDateTime;

void setup() {

  FastLED.delay(3000);
  FastLED.addLeds<WS2812B, DATA_PIN, GRB>(LEDs, NUM_LEDS);  

  Serial.begin(115200);          
  delay(10);
  Serial.println("\r\n");

  startWiFi();
  startUDP();

  if(!WiFi.hostByName(NTPServerName, timeServerIP)) { 
    Serial.println("DNS lookup failed. Rebooting.");
    Serial.flush();
    ESP.reset();
  }
  Serial.print("Time server IP:\t");
  Serial.println(timeServerIP);
  
  Serial.println("\r\nSending NTP request ...");
  sendNTPpacket(timeServerIP);  
}

void loop() {
  unsigned long currentMillis = millis();

  if (currentMillis - prevNTP > intervalNTP) { // If a minute has passed since last NTP request
    prevNTP = currentMillis;
    Serial.println("\r\nSending NTP request ...");
    sendNTPpacket(timeServerIP);               // Send an NTP request
  }

  uint32_t time = getTime();                   // Check if an NTP response has arrived and get the (UNIX) time
  if (time) {                                  // If a new timestamp has been received
    timeUNIX = time;
    Serial.print("NTP response:\t");
    Serial.println(timeUNIX);
    lastNTPResponse = currentMillis;
  } else if ((currentMillis - lastNTPResponse) > 3600000) {
    Serial.println("More than 1 hour since last NTP response. Rebooting.");
    Serial.flush();
    ESP.reset();
  }

  uint32_t actualTime = timeUNIX + (currentMillis - lastNTPResponse)/1000;
  if (actualTime != prevActualTime && timeUNIX != 0) { // If a second has passed since last update
    prevActualTime = actualTime;
    convertTime(actualTime);

    for (int i=0; i<NUM_LEDS; i++) 
      LEDs[i] = CRGB::Black;

    int second = getLEDMinuteOrSecond(currentDateTime.second);
    int minute = getLEDMinuteOrSecond(currentDateTime.minute);
    int hour = getLEDHour(currentDateTime.hour, currentDateTime.minute);

    // Set "Hands"
    LEDs[second] = colorSecond;
    LEDs[minute] = colorMinute;  
    LEDs[hour] = colorHour;  

    // Hour and min are on same spot
    if ( hour == minute)
      LEDs[hour] = colorHourMinute;

    // Hour and sec are on same spot
    if ( hour == second)
      LEDs[hour] = colorHourSecond;

    // Min and sec are on same spot
    if ( minute == second)
      LEDs[minute] = colorMinuteSecond;

    // All are on same spot
    if ( minute == second && minute == hour)
      LEDs[minute] = colorAll;

    if ( night() && USE_NIGHTCUTOFF == true )
      FastLED.setBrightness (NIGHTBRIGHTNESS); 

    FastLED.show();
  }  
}

byte getLEDHour(byte hours, byte minutes) {
  if (hours > 12)
    hours = hours - 12;

  byte hourLED;
  if (hours <= 5) 
    hourLED = (hours * 5) + 30;
  else
    hourLED = (hours * 5) - 30;

  if (USE_LED_MOVE_BETWEEN_HOURS == true) {
    if        (minutes >= 12 && minutes < 24) {
      hourLED += 1;
    } else if (minutes >= 24 && minutes < 36) {
      hourLED += 2;
    } else if (minutes >= 36 && minutes < 48) {
      hourLED += 3;
    } else if (minutes >= 48) {
      hourLED += 4;
    }
  }

  return hourLED;  
}

byte getLEDMinuteOrSecond(byte minuteOrSecond) {
  if (minuteOrSecond < 30) 
    return minuteOrSecond + 30;
  else 
    return minuteOrSecond - 30;
}

void startWiFi() { 
  wifiMulti.addAP(ssid, pass);   

  Serial.println("Connecting");
  byte i = 0;
  while (wifiMulti.run() != WL_CONNECTED) {  
    delay(250);
    Serial.print('.');
    LEDs[i++] = CRGB::Green;
    FastLED.show();    
  }
  Serial.println("\r\n");
  Serial.print("Connected to ");
  Serial.println(WiFi.SSID());             
  Serial.print("IP address:\t");
  Serial.print(WiFi.localIP());            
  Serial.println("\r\n");
}

void startUDP() {
  Serial.println("Starting UDP");
  UDP.begin(123);                          // Start listening for UDP messages on port 123
  Serial.print("Local port:\t");
  Serial.println(UDP.localPort());
  Serial.println();
}

uint32_t getTime() {
  if (UDP.parsePacket() == 0) { // If there's no response (yet)
    return 0;
  }
  UDP.read(NTPBuffer, NTP_PACKET_SIZE); // read the packet into the buffer
  // Combine the 4 timestamp bytes into one 32-bit number
  uint32_t NTPTime = (NTPBuffer[40] << 24) | (NTPBuffer[41] << 16) | (NTPBuffer[42] << 8) | NTPBuffer[43];
  // Convert NTP time to a UNIX timestamp:
  // Unix time starts on Jan 1 1970. That's 2208988800 seconds in NTP time:
  const uint32_t seventyYears = 2208988800UL;
  // subtract seventy years:
  uint32_t UNIXTime = NTPTime - seventyYears;
  return UNIXTime;
}

void sendNTPpacket(IPAddress& address) {
  memset(NTPBuffer, 0, NTP_PACKET_SIZE);  // set all bytes in the buffer to 0
  // Initialize values needed to form NTP request
  NTPBuffer[0] = 0b11100011;   // LI, Version, Mode
  // send a packet requesting a timestamp:
  UDP.beginPacket(address, 123); // NTP requests are to port 123
  UDP.write(NTPBuffer, NTP_PACKET_SIZE);
  UDP.endPacket();
}

void convertTime(uint32_t time) {
  // Correct time zone
  time += (3600 * timeZone);
  
  currentDateTime.second = time % 60;
  currentDateTime.minute = time / 60 % 60;
  currentDateTime.hour   = time / 3600 % 24;
  time  /= 60;  // To minutes
  time  /= 60;  // To hours
  time  /= 24;  // To days
  currentDateTime.dayofweek = ((time + 4) % 7) + 1;
  int year = 0;
  int days = 0;
  while ((unsigned)(days += (LEAP_YEAR(year) ? 366 : 365)) <= time) {
    year++;
  }
  days -= LEAP_YEAR(year) ? 366 : 365;
  time  -= days; // To days in this year, starting at 0  
  days = 0;
  byte month = 0;
  byte monthLength = 0;
  for (month = 0; month < 12; month++) {
    if (month == 1) { // February
      if (LEAP_YEAR(year)) {
        monthLength = 29;
      } else {
        monthLength = 28;
      }
    } else {
      monthLength = monthDays[month];
    }
  
    if (time >= monthLength) {
      time -= monthLength;
    } else {
      break;
    }
  }
 
  currentDateTime.day = time + 1;
  currentDateTime.year = year + 1970;
  currentDateTime.month = month + 1;  

  // Correct European Summer time
  if (summerTime()) {
    currentDateTime.hour += 1;
  }

#ifdef DEBUG_ON
  Serial.print(currentDateTime.year);
  Serial.print(" ");
  Serial.print(currentDateTime.month);
  Serial.print(" ");
  Serial.print(currentDateTime.day);
  Serial.print(" ");
  Serial.print(currentDateTime.hour);
  Serial.print(" ");
  Serial.print(currentDateTime.minute);
  Serial.print(" ");
  Serial.print(currentDateTime.second);
  Serial.print(" day of week: ");
  Serial.print(currentDateTime.dayofweek);
  Serial.print(" summer time: ");
  Serial.print(summerTime());
  Serial.print(" night time: ");
  Serial.print(night());  
  Serial.println();
#endif  
}

boolean summerTime() {

  if (currentDateTime.month < 3 || currentDateTime.month > 10) return false;  // No summer time in Jan, Feb, Nov, Dec
  if (currentDateTime.month > 3 && currentDateTime.month < 10) return true;   // Summer time in Apr, May, Jun, Jul, Aug, Sep
  if (currentDateTime.month == 3 && (currentDateTime.hour + 24 * currentDateTime.day) >= (3 +  24 * (31 - (5 * currentDateTime.year / 4 + 4) % 7)) || currentDateTime.month == 10 && (currentDateTime.hour + 24 * currentDateTime.day) < (3 +  24 * (31 - (5 * currentDateTime.year / 4 + 1) % 7)))
  return true;
    else
  return false;
}

boolean night() {
  
  if (currentDateTime.hour >= NIGHTCUTOFF && currentDateTime.hour <= MORNINGCUTOFF) 
    return true;    
}

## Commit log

2019-03-16 Added ino file
    [Box.stl, Cover Large.stl, Cover Small.stl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]
2019-03-21 Fixed timezone and EU summertime and added option to change colors
    [RoundLEDClock.ino]
2019-04-02 Added segments with thinker walls and a complete ring for larger 3D printers
    [Segment complete thicker wall.stl, Segment complete.stl, Segment thicker wall.stl]
2019-05-04 Renamed ino file to prevent Arduino folder creation and manually merged night brightness PR from tulipy
    [Round-LED-Clock.ino]
2019-05-10 Added the option to move the red hour LED between hours
2019-10-06 Changed the ntp server to a local one because it didn't work anymore. Also changed the update frequency
    [Round-LED-Clock.ino]
